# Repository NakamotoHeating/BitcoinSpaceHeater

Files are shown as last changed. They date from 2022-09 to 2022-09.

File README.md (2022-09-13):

# BitcoinSpaceHeater

Files and build instructions for the #BitcoinSpaceHeater see https://twitter.com/NakamotoHeating/ to learn more.

## Idea

- Create a space heating solution based on an Antminer S9 which is completely or near silent.
- Reuse existing parts of a stock S9
- Use parts that are easily and widely available or are 3D printed
- Simple and low complex solution. Goal for anybody to build this at home
- Completely Open Source

## Build Video

Bitcoin Space Heater Build Video (https://www.youtube.com/watch?v=tFrhJgNJKrE)

## Injector Plates

The injector plates are designed by [@Adrian_van_Wijk](https://twitter.com/Adrian_van_Wijk). And freely available under the `stl` and `stp` Folder.
We strongly suggest to print them with ABS, as PLA get malleable (glass transition temperature) at 60C/140F which could cause problems when the Oil gets to 60C+ temperatures.

Experience shows that the threads and pipe of the bottom cover are better printed without support. For this there are `3mf` files attached that have the required support inhibitors and settings for an Ender 3V2 printer with ABS (modify to your needs).

## Parts list

partslist-min

1. Antminer S9
2. Power Supply (we used Antminer APW3++)
3. ABS 3D printed Top Cap
4. ABS 3D printed Bottom Cover
5. 6x ABS 3D printed Power Flow Plug
6. 4x 12mm Spring Clamp (https://www.amazon.com/dp/B0753YG7SJ)
7. 3x G1/4 Tube Barb Connector (https://www.amazon.com/gp/product/B09KZMMC1N/)
8. 360mm Computer Radiator (https://www.amazon.com/dp/B079DHJ91F) & Screws (come with Radiator)
9. 120mm Fans (we used Noctua https://www.amazon.com/dp/B00650P2ZC) and Fan Y-Cable (come with Noctua fans)
10. 1/2" OD x 3/8" ID Polyethylene Tube (https://www.homedepot.com/p/Everbilt-1-2-in-O-D-x-3-8-in-I-D-x-25-ft-Polyethylene-Tube-301844/207144259)
11. 120mm Fan Grills (we used two coming with the S9, plus bought one https://www.amazon.com/Bgears-Cooling-Fan-Grill-120mm/dp/B00315C02W)
12. 12V Submersible Pump (we used https://www.amazon.com/dp/B09Y2H3D71 but technically any pump with more than 800L/H and rated to higher temperatures than 60C should work)

## Tools list

A. Tube cutter  
B. 5min Epoxy  
C. Soldering Iron & Solder  
D. Wire Stripper  
E. Screwdriver  
F. Nose plier  
G. Side cutting plier  
H. Two containers  
I. Heat Gun  
J. Brush

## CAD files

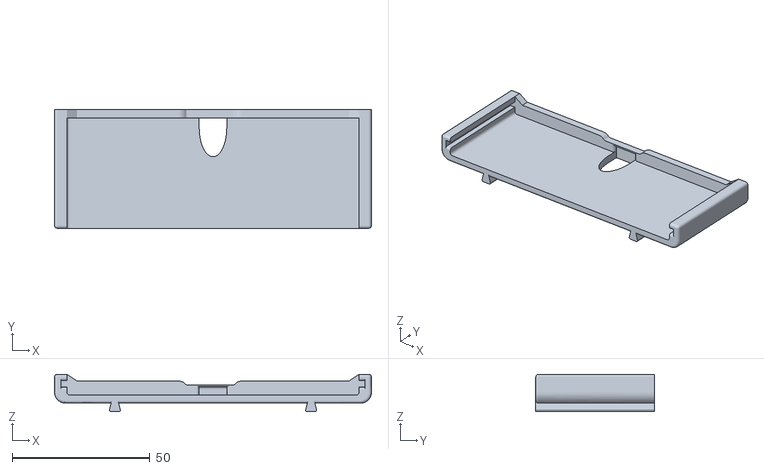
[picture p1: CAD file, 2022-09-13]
stl/s9-controler-mount.stl
115.0 x 43.0 x 13.6

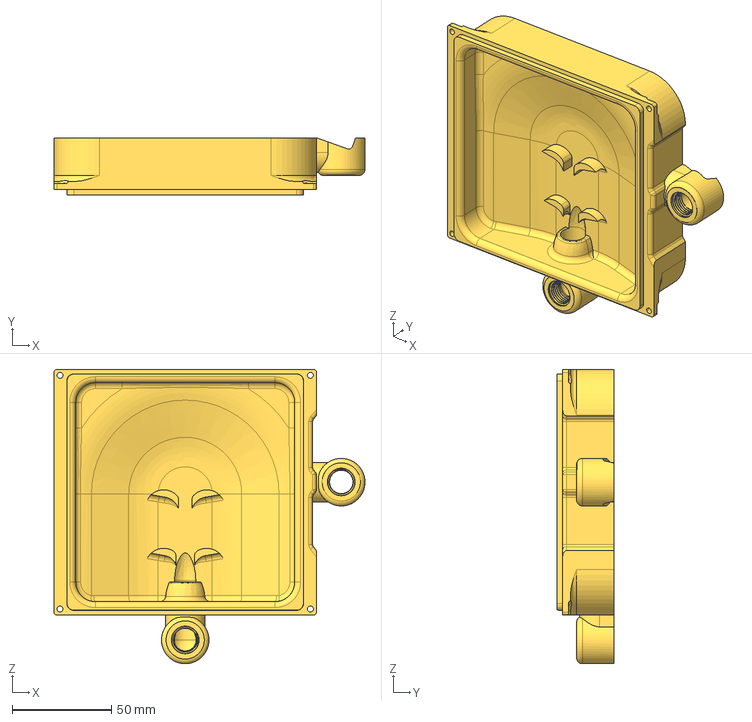
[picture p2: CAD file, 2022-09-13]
stp/Bottom-Cover-In.stp
156.9 x 29.0 x 148.5 mm

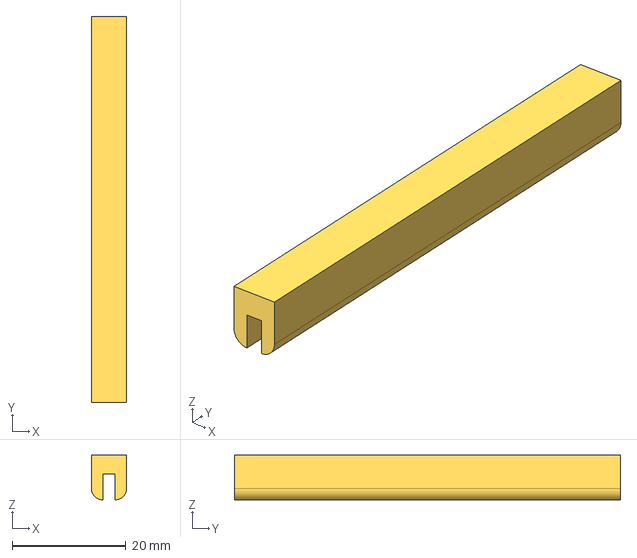
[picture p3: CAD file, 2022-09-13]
stp/Power-flow-plug.stp
6.20 x 68.0 x 7.88 mm

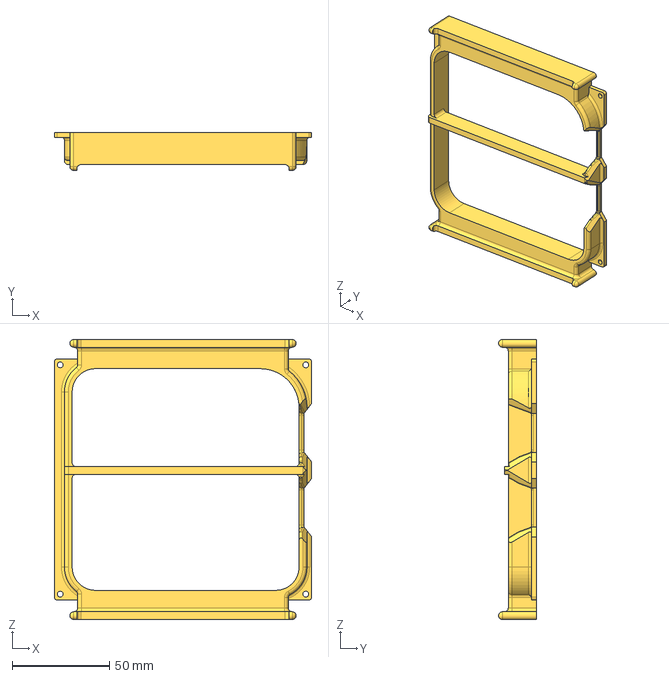
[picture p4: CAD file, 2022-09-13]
stp/Top-cap-2.stp
132.4 x 19.5 x 144.0 mm

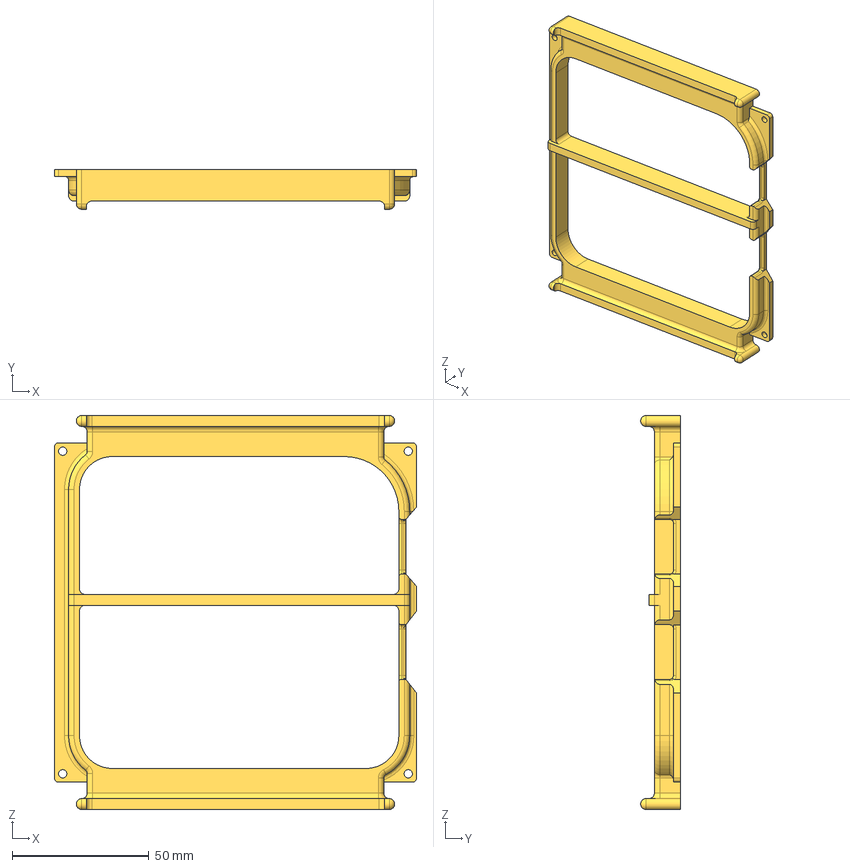
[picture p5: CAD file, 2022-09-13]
stp/Top-cap.stp
132.4 x 14.5 x 144.0 mm

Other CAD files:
3mf/Bottom-Cover-In.3mf
stl/Bottom-Cover-In.stl
stl/Power-flow-plug.stl
stl/Top-cap-2.stl

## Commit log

2022-07-23 stl, 3mf and first readme
    [Block-Cover-Out-ABS.3mf, Block-Cover-Out.stl, Outlet-Cover-ABS.3mf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]
2022-09-13 update all files to newest version
    [Block-Cover-Out-ABS.3mf, Block-Cover-Out.stl, Bottom-Cover-In.3mf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]
